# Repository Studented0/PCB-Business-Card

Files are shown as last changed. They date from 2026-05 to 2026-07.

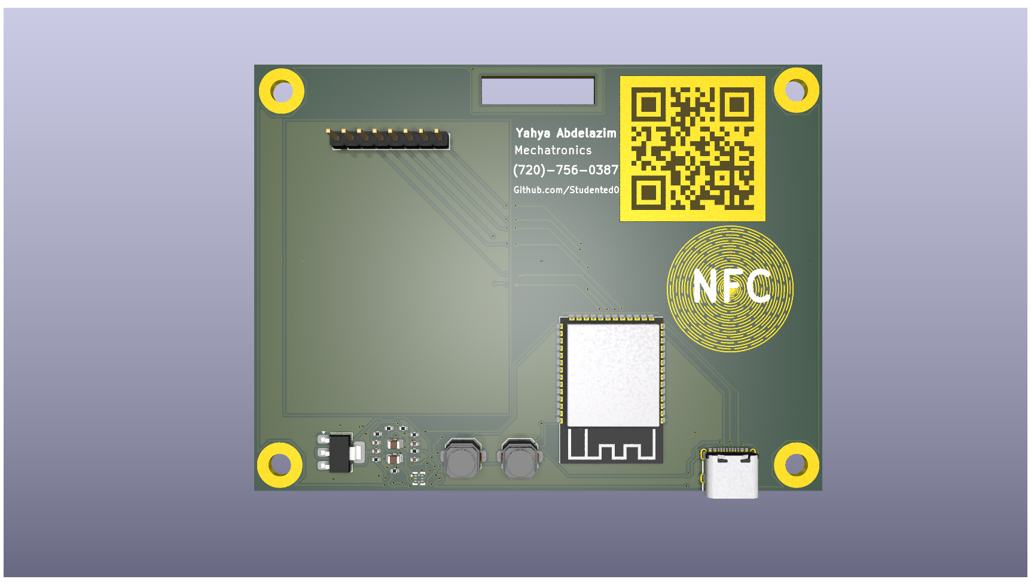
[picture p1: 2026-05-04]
productionold/lanyardpcbcard.png

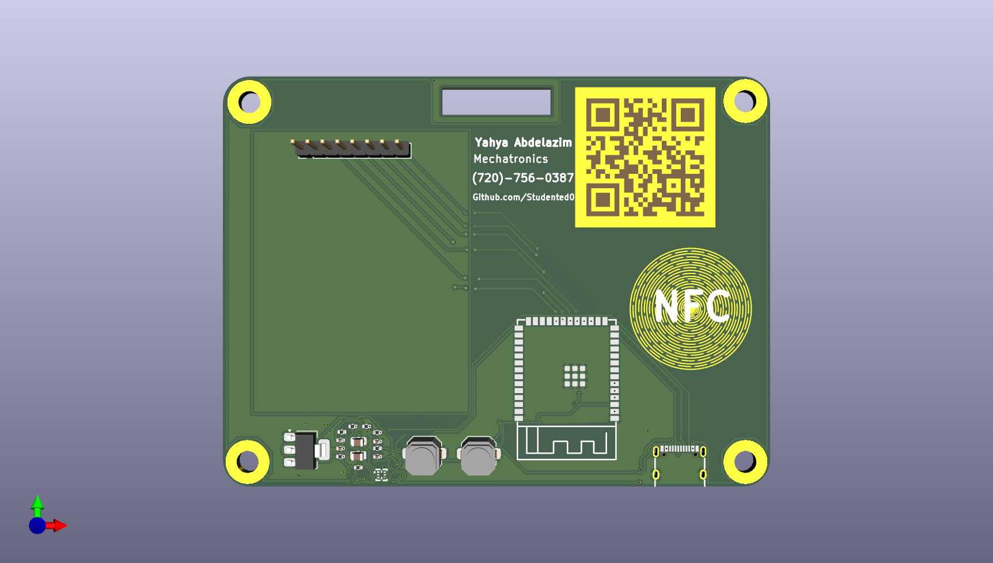
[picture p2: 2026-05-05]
Renders and CAD/lanyardpcbcard.png

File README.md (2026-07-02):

[PCB Business Card-bom.csv](https://github.com/user-attachments/files/27329266/PCB.Business.Card-bom.csv)
# PCB-Business-Card
 
A PCB Business card that shows your Spotify activity using lanyard in real time. Tap the card with a phone to show what song is playing on Spotify.
 
Powered over USB-C from a phone or any power bank. Connects to a phone hotspot (or any wifi) for the Lanyard WebSocket. 
 
## Screenshots


lanyardpcbcard

## Why I built this
 
I wanted a business card that has a cool twist. Plain cards feel boring to show and they are all the same. This one shows what I'm listening to, lets someone tap it to hear the same song, and has my GitHub a QR scan away. Business cards are supposed to grab people's attention, and I would say this one is different than other business cards.
 
## Hardware
 The ESP32 rewrites the NDEF URL every time a track changes over I2C, NT3H2111 (NFC Module) has I2C and RF interface simultaneously. When you are playing something NFC goes to spotify when nothing is playing goes to GitHub (for now). 100x75mm PCB. USB-C powers it with any power bank (im personally planning to use my phone). ESP32 is going to be hand soldered to save money but everything else is JLCPCB assembly 
 
## Wiring
 
| Signal | GPIO |
|---|---|
| DISP_MOSI | IO11 |
| DISP_SCLK | IO12 |
| DISP_CS | IO10 |
| DISP_DC | IO13 |
| DISP_RST | IO14 |
| DISP_BLK | IO9 |
| NFC_SDA | IO5 |
| NFC_SCL | IO6 |
| NFC_FD | IO4 |
| USB_DN | IO19 |
| USB_DP | IO20 |
| BOOT | IO0 |
| RESET | EN |
 
## Firmware
 
`firmware/main.ino` 
 
Libraries needed: TFT_eSPI, TJpg_Decoder, ArduinoWebsockets, ArduinoJson. Board: ESP32S3 Dev Module.
 
## Bill of Materials
 
SMD parts assembled by JLCPCB. ESP32 and the display are sourced separately.
 
| Component | Qty | LCSC | Note |
|---|-----|---|---|
| 100nF 0402 cap | 3 | C1525 | Basic |
| 10µF 0805 cap | 2 | C15850 | Basic |
| 56pF 0402 cap | 1 | C107007 | Extended — antenna tuning |
| 5.1kΩ 0402 resistor | 2 | C25905 | Basic — USB-C CC |
| 10kΩ 0402 resistor | 3 | C25744 | Basic — pullups |
| 4.7kΩ 0402 resistor | 2 | C25900 | Basic — I2C pullups |
| AMS1117-3.3 SOT-223 | 1 | C6186 | Basic |
| NT3H2111W0FHKH XQFN-8 | 1 | C710403 | Extended — NFC |
| TYPE-C 16PIN 2MD | 1 | C2765186 | Extended — USB-C |
| Tactile switch SMD | 2 | — | Extended |
 Name,Purpose,Quantity,Total Cost (USD),Link,Distributor
"Display","Displaying",1,14.00,"https://www.amazon.com/gp/product/B0GL1SWYP4/ref=ox_sc_act_title_1?smid=A2Z10KY0342329&psc=1","Amazon"
"ESP32-S3-WROOM-1-N4","microcontroller",1,5.21,"https://www.digikey.com/en/products/detail/espressif-systems/ESP32-S3-WROOM-1-N4/16162639","DIGIKEY"
"JLCPCB","PCB",1,25.59,"","JLCPCB"
| Component | Qty | Source |
|---|-----|---|
| ESP32-S3-WROOM-1-N8| 1 | Mouser Electronics |
| 2.0" ST7789V IPS 240×320 | 1 | Amazon |
 
## Repository Structure
 
```
PCB-Business-Card/
├── Firmware/
│   └── main.ino
├── lanyardpcbcard-backups/
├── libs/
│   └── easyeda/
│       ├── easyeda.3dshapes/
│       ├── easyeda.pretty/
│       └── easyeda.kicad_sym
├── production/
│   ├── backups/
│   ├── CPL-lanyardpcbcard.csv
│   ├── bom.csv
│   ├── lanyardpcbcard.step
│   ├── lanyardpcbcard.zip
│   └── ...
├── LICENSE
├── README.md
├── lanyardpcbcard.kicad_pcb
├── lanyardpcbcard.kicad_pro
├── lanyardpcbcard.kicad_sch
└── lanyardpcbcard.kicad_prl
```
 
## License
 
[MIT](LICENSE)

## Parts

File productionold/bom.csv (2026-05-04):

Designator | Footprint | Quantity | Value | LCSC Part #
C1, C3 | 0805 | 2 | 10µF
C2, C4, C5 | 0402 | 3 | 100nF
C6 | 0402 | 1 | 56pF
J1 | PinHeader_1x08_P2.54mm_Vertical | 1 | DISPLAY
R1, R2 | 0402 | 2 | 5.1k
R3, R4, R7 | 0402 | 3 | 10k
R5, R6 | 0402 | 2 | 4.7k
SW1 | SW_Push_1TS009xxxx-xxxx-xxxx_6x6x5mm | 1 | Reset
SW2 | SW_Push_1TS009xxxx-xxxx-xxxx_6x6x5mm | 1 | Boot
U1 | SOT-223-3_TabPin2 | 1 | AMS1117-3.3
U2 | WIRELM-SMD_ESP32-S3-WROOM-1 | 1 | ESP32-S3-WROOM-1 | C2913202
U3 | XQFN-8_L1.6-W1.6-P0.50-BL_NT3H2111W0FHKH | 1 | NT3H2111W0FHKH | C710403
USB1 | USB-C-SMD_TYPE-C-16PIN-2MD-073 | 1 | TYPE-C 16PIN 2MD | C2765186

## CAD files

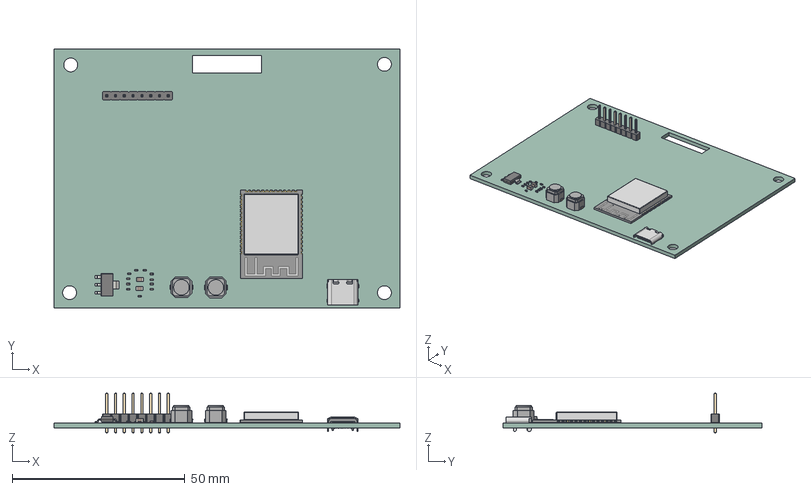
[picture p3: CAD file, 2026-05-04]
productionold/lanyardpcbcard.step
100.0 x 75.0 x 11.5 mm
C_0805_2012Metric x 2
R_0402_1005Metric x 7
C_0402_1005Metric x 4
pin_1 x 2
pin_2 x 2
PinHeader_1x08_P2.54mm_Vertical
SOT-223
USB-C-SMD_TYPE-C-6PIN-2MD-073
WIRELM-SMD_ESP32-S3-WROOM-1
lanyardpcbcard_PCB

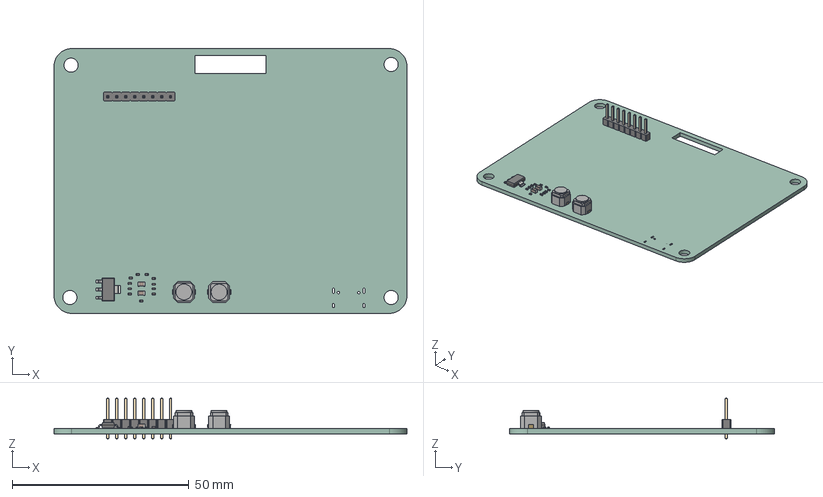
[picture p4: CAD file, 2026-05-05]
Renders and CAD/lanyardpcbcard.step
100.0 x 75.0 x 11.5 mm
C_0805_2012Metric x 2
R_0402_1005Metric x 7
C_0402_1005Metric x 4
pin_1 x 2
pin_2 x 2
PinHeader_1x08_P2.54mm_Vertical
SOT-223
lanyardpcbcard_PCB

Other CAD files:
Renders and CAD/lanyardpcbcard.stl
productionold/lanyardpcbcard.stl

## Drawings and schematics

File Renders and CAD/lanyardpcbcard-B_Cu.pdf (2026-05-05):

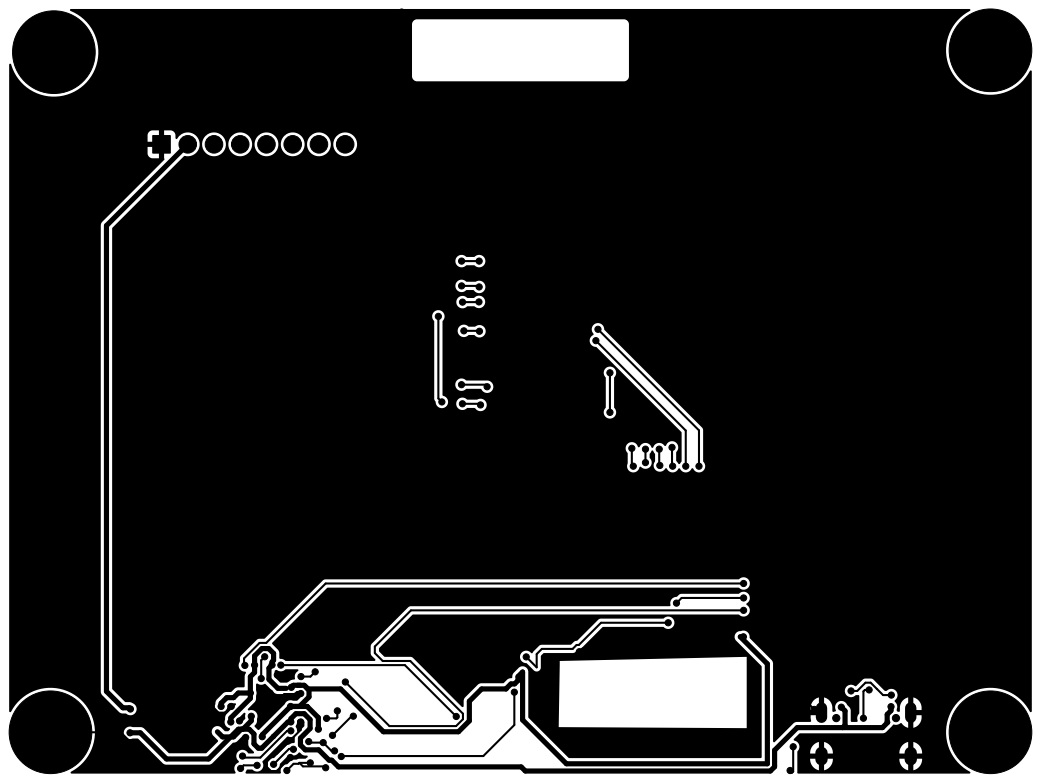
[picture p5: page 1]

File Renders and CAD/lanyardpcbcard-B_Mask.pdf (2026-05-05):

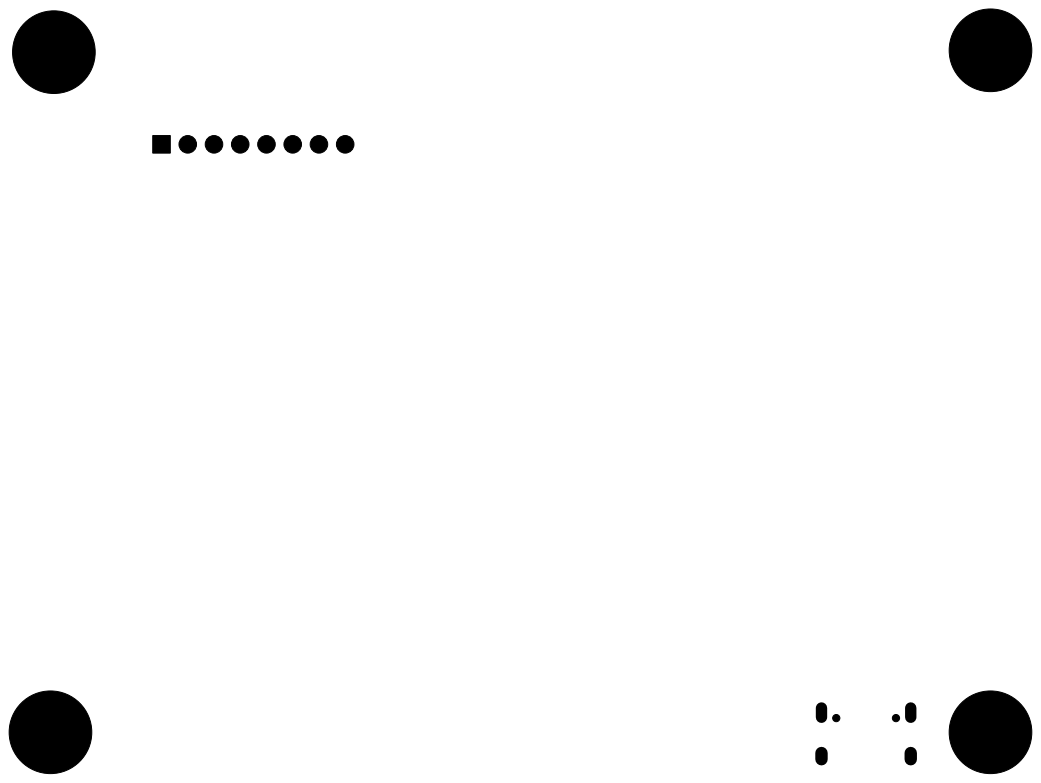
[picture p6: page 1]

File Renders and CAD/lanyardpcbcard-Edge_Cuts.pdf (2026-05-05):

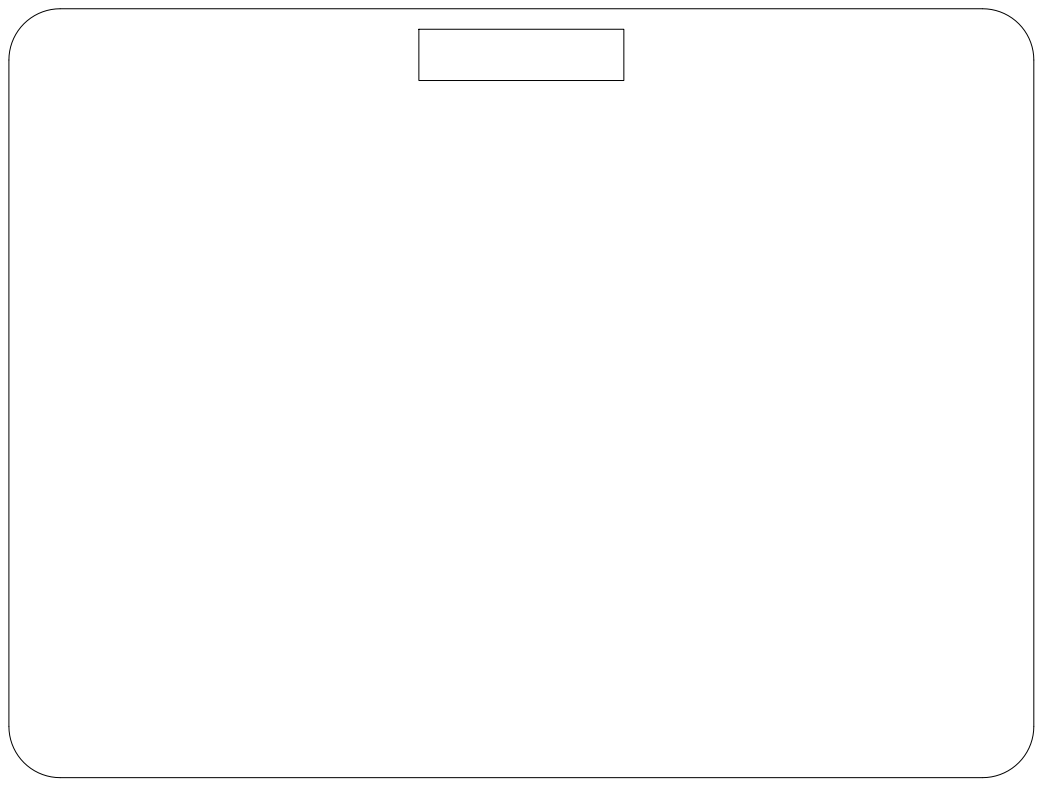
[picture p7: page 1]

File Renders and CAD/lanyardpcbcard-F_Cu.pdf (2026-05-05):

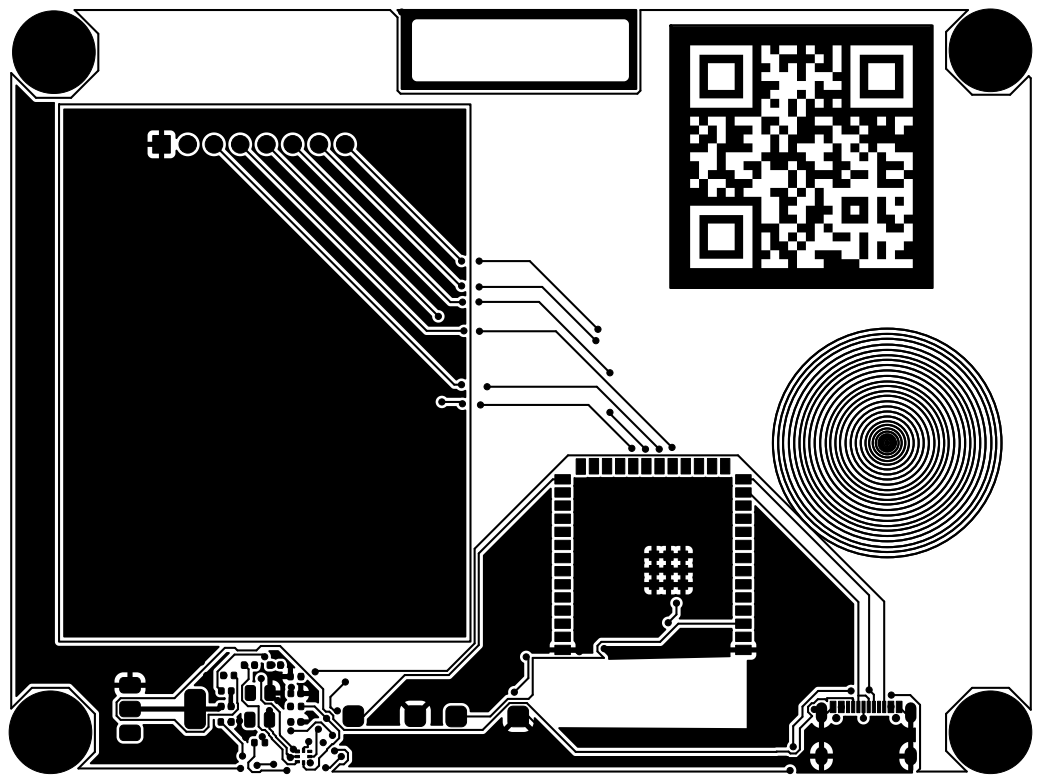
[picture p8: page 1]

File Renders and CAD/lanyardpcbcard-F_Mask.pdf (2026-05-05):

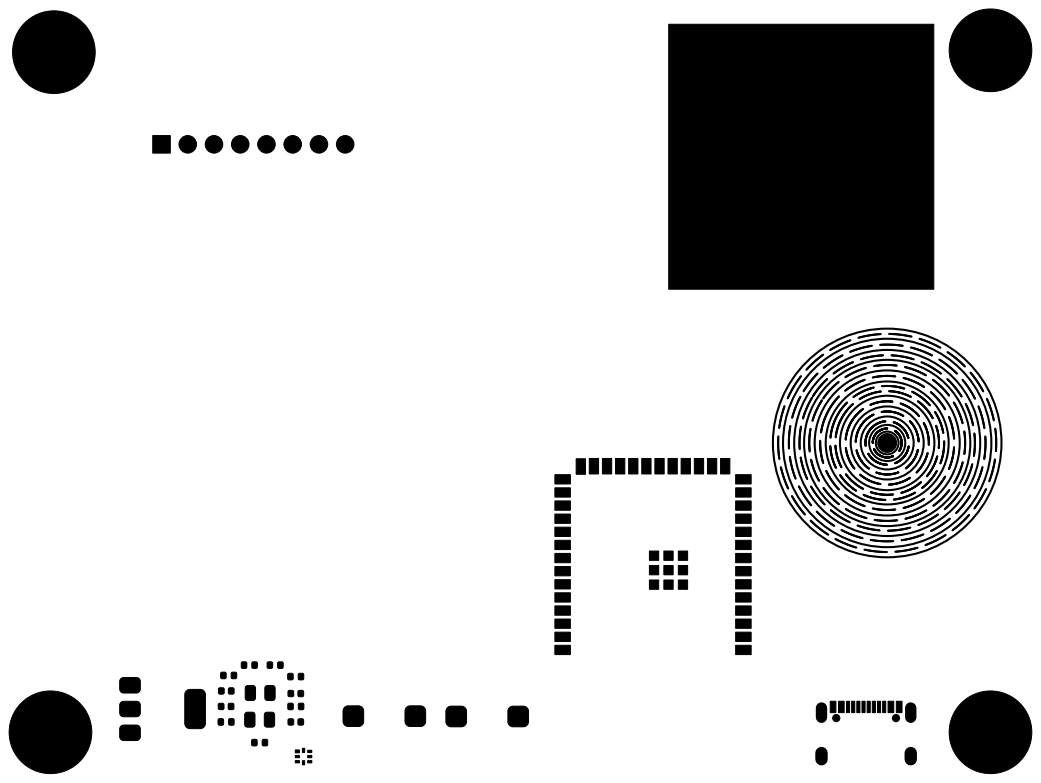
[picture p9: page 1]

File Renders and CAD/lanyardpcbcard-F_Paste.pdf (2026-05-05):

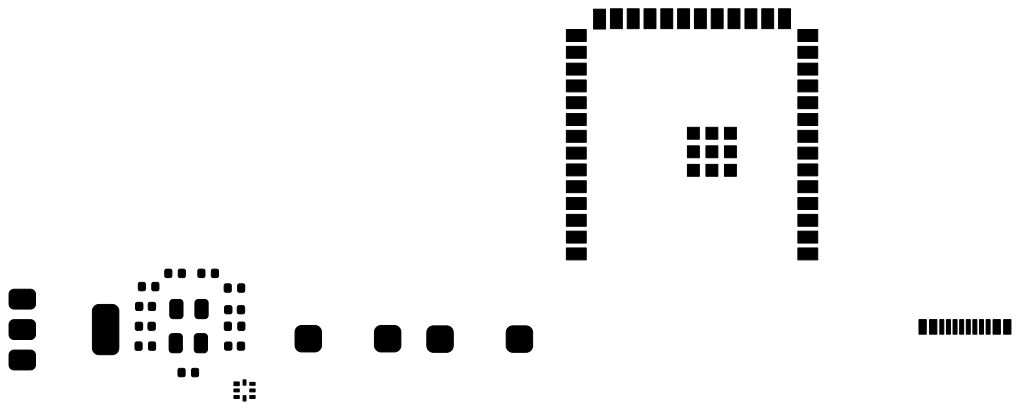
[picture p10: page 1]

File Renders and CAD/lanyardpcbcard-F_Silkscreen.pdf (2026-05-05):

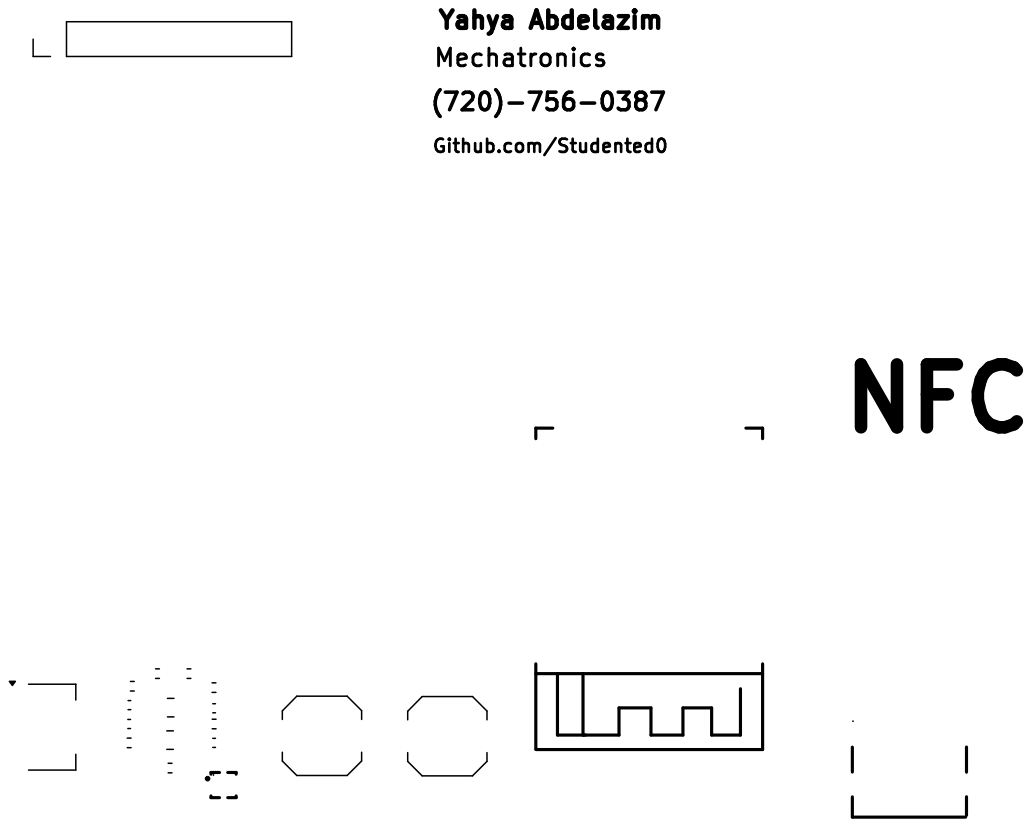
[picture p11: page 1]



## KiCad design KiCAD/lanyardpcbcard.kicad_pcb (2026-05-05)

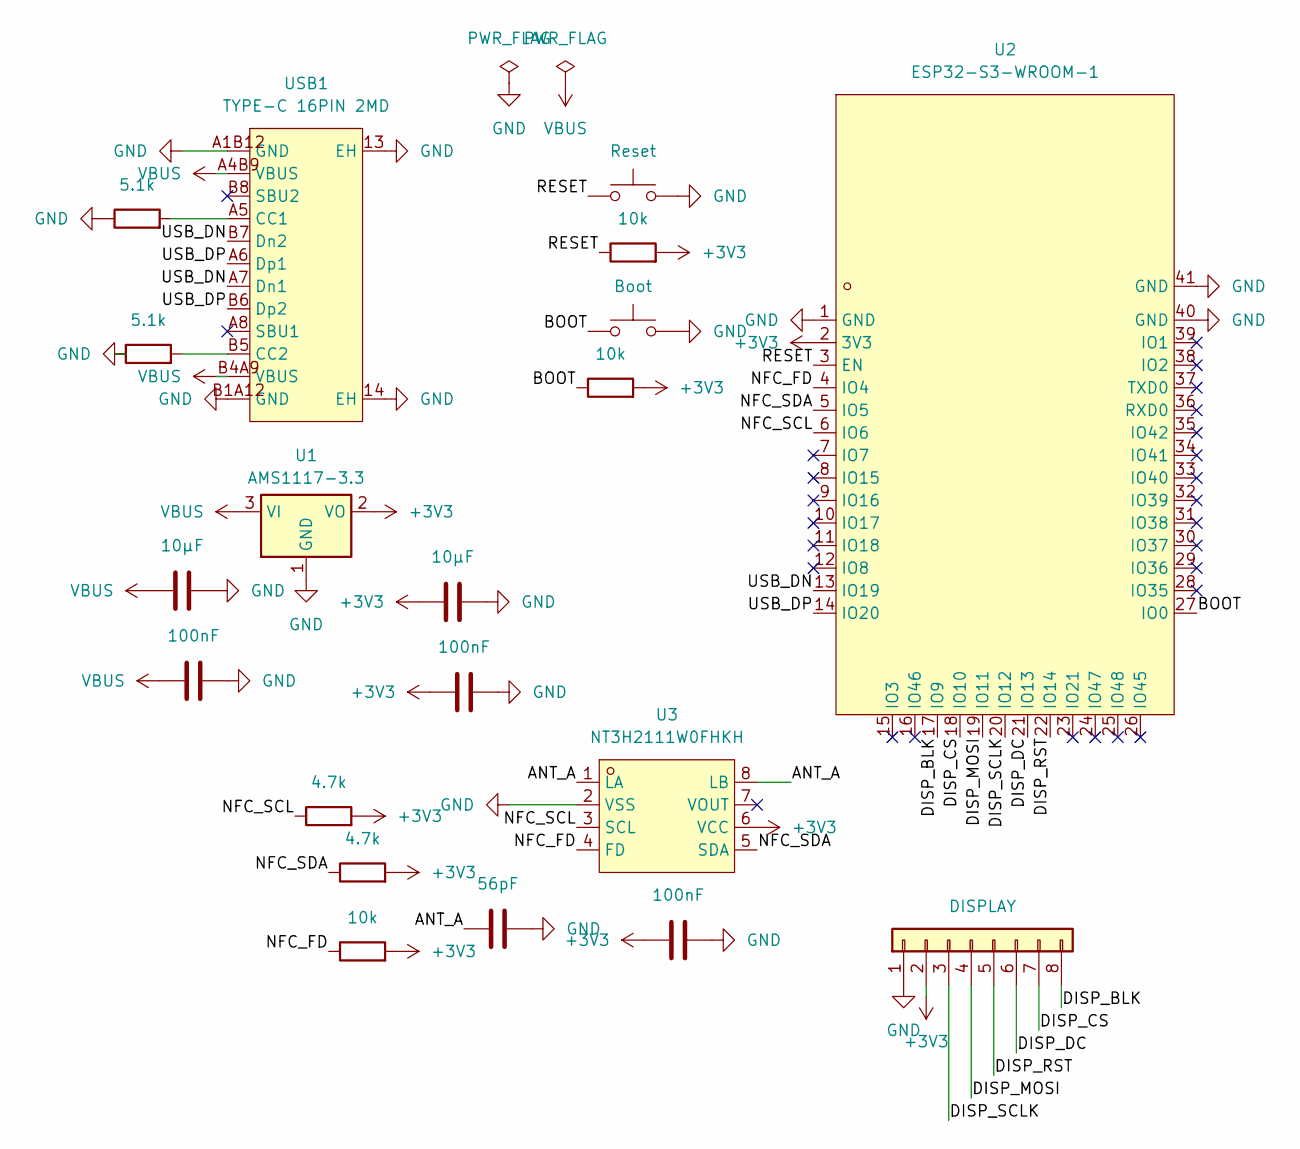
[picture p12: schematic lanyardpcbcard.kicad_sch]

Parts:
C1, C3: 10µF; C_0805_2012Metric
C2, C4, C5: 100nF; C_0402_1005Metric
C6: 56pF; C_0402_1005Metric
J1: DISPLAY; PinHeader_1x08_P2.54mm_Vertical
R1, R2: 5.1k; R_0402_1005Metric
R3, R4, R7: 10k; R_0402_1005Metric
R5, R6: 4.7k; R_0402_1005Metric
SW1: Reset; SW_Push_1TS009xxxx-xxxx-xxxx_6x6x5mm
SW2: Boot; SW_Push_1TS009xxxx-xxxx-xxxx_6x6x5mm
U1: AMS1117-3.3; SOT-223-3_TabPin2
U2: ESP32-S3-WROOM-1; WIRELM-SMD_ESP32-S3-WROOM-1; MPN ESP32-S3-WROOM-1-N16R8; LCSC Part C2913202
U3: NT3H2111W0FHKH; XQFN-8_L1.6-W1.6-P0.50-BL_NT3H2111W0FHKH; MPN NT3H2111W0FHKH; LCSC Part C710403
USB1: TYPE-C 16PIN 2MD; USB-C-SMD_TYPE-C-16PIN-2MD-073; MPN TYPE-C 16PIN 2MD(073); LCSC Part C2765186

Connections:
+3V3: C3.1, C4.1, C5.1, J1.2, R3.2, R4.2, R5.2, R6.2, R7.2, U1.2 (VO), U2.2 (3V3), U3.6 (VCC)
/ANT_A: C6.1, U3.1 (LA), U3.8 (LB)
/BOOT: R4.1, SW2.1, U2.27 (IO0)
/DISP_BLK: J1.8, U2.17 (IO9)
/DISP_CS: J1.7, U2.18 (IO10)
/DISP_DC: J1.6, U2.21 (IO13)
/DISP_MOSI: J1.4, U2.19 (IO11)
/DISP_RST: J1.5, U2.22 (IO14)
/DISP_SCLK: J1.3, U2.20 (IO12)
/NFC_FD: R7.1, U2.4 (IO4), U3.4 (FD)
/NFC_SCL: R5.1, U2.6 (IO6), U3.3 (SCL)
/NFC_SDA: R6.1, U2.5 (IO5), U3.5 (SDA)
/RESET: R3.1, SW1.1, U2.3 (EN)
/USB_DN: U2.13 (IO19), USB1.A7 (Dn1), USB1.B7 (Dn2)
/USB_DP: U2.14 (IO20), USB1.A6 (Dp1), USB1.B6 (Dp2)
GND: C1.2, C2.2, C3.2, C4.2, C5.2, C6.2, J1.1, R1.1, R2.1, SW1.2, SW2.2, U1.1 (GND), U2.1 (GND), U2.40 (GND), U2.41 (GND), U3.2 (VSS), USB1.13 (EH), USB1.14 (EH), USB1.A1B12 (GND), USB1.B1A12 (GND)
unnamed: R1.2, USB1.A5 (CC1)
unnamed: R2.2, USB1.B5 (CC2)
VBUS: C1.1, C2.1, U1.3 (VI), USB1.A4B9 (VBUS), USB1.B4A9 (VBUS)

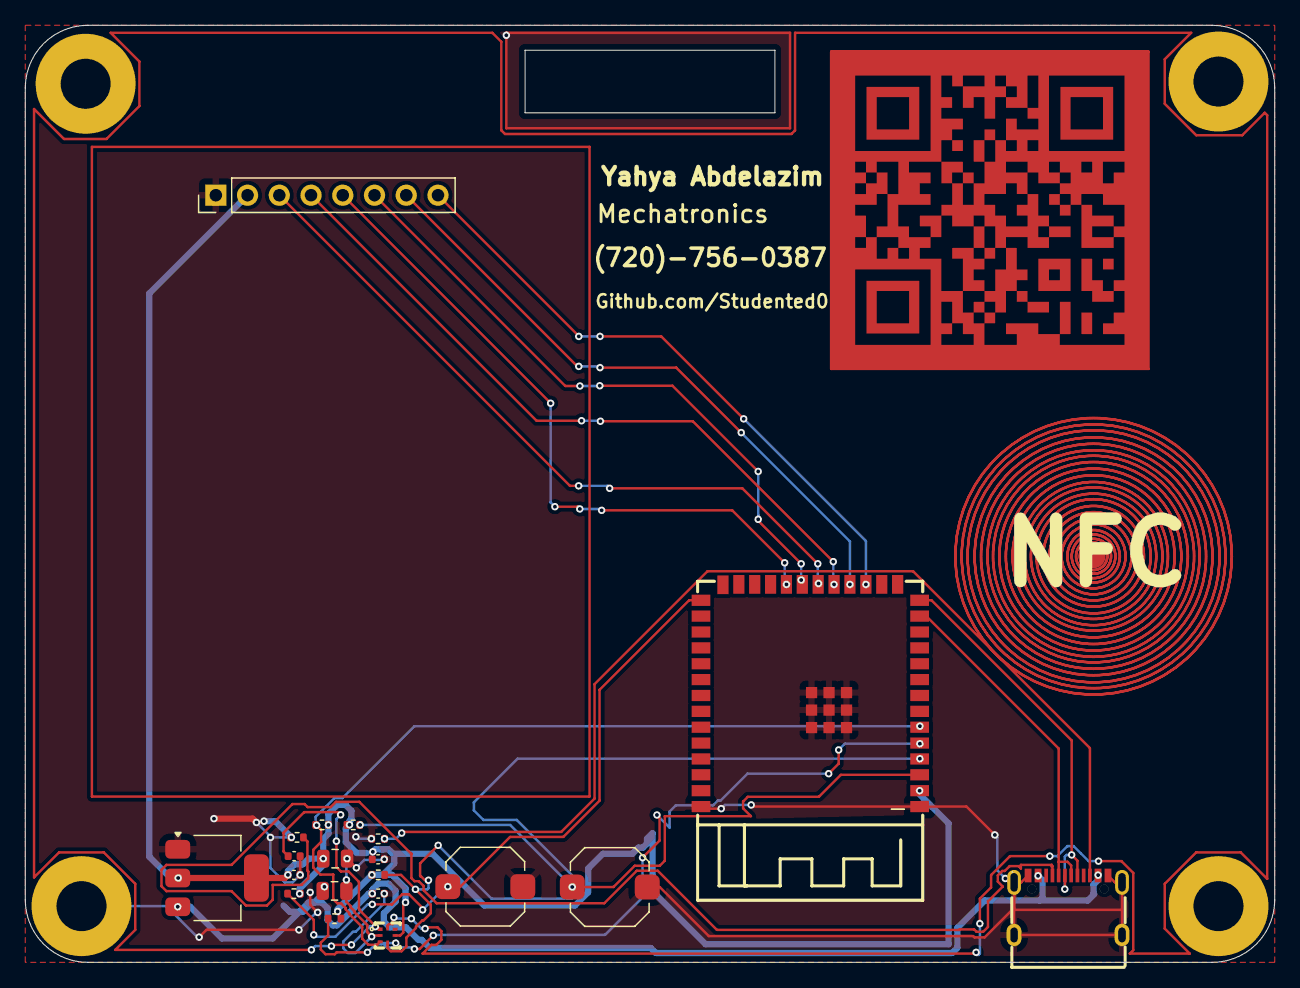
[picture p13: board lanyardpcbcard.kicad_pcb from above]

Board: 2 copper layers, 100.0 x 75.0 mm, 20 parts (0 on the bottom side), 19 nets.

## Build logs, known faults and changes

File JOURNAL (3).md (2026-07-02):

<!--
  This journal is auto generated by Stasis.
-->

# 5/5/2026 4 PM - Updated PCB, README, And ordered parts

_Time spent: 1h_

In this session I rewrote the README fully by hand, FIlleted the PCB, and ordered all the parts as I will request reimbursment of the 50 and pay the 6 on my own. The updated PCB is below. (It will be Black)
lanyardpcbcard



# 5/4/2026 3 AM - JLCPCB, BOM, and GitHub

_Time spent: 3.25h_

Exported everything using the Fabrication Toolkit plugin for KiCad. The BOM matching on JLCPCB was not very easy. Several parts didn't auto-match correctly. The resistors showed zero stock even though they exist as basic parts, had to search each value manually and select them. The display header got matched to a completely wrong part, a 1.28" round LCD module, so I deselected it entirely since I'm plugging the display in myself anyway.
Then the price came up as $67. The breakdown was $25 setup fee, $16 feeder loading fee, and the rest was components and assembly. Switching to economic assembly dropped it significantly but the ESP32-S3-WROOM-1 is marked as Standard Only on JLCPCB . So I removed it from the assembly order and I'll solder it myself when the board arrives. Castellated pads are actually not that hard to hand solder with flux. That brought the price down to around $21 for the assembled board without the ESP32.
The ESP32 I'm ordering separately from DigiKey. $5.21 for the chip plus $6.99 FedEx Ground shipping, $12.72 total. Annoying to pay separate shipping but it's still way cheaper than the $67 standard assembly quote.
Setting up the GitHub repo and pushing everything was straightforward. The repo has the KiCad files in the root, production files in the production folder, firmware in the Firmware folder, and the easyeda library in libs/easyeda. BOM.csv in the root links to the LCSC part numbers for everything JLCPCB assembles.





# 5/4/2026 3 AM - PCB Layout and Routing

_Time spent: 3.25h_

Layout started with setting the board size to 100×75mm. That fits JLCPCB's economic assembly limit and is pretty similar to a SATA SSD.
The first thing I placed was the display connector. The 2.0" ST7789V module from Amazon has a footprint that takes up almost the entire top half of the board. I didn't expect that. It actually worked out well because now the card has a clear right half that's just the screen and a left half where all the components live. 
I added a copper QR code using KiCad's image converter tool. That process was a disaster. The first import came in as a giant pink rectangle covering half the board. Try again with different scale. Then the inversion was wrong, the QR was solid copper with dark cutouts instead of copper squares on green. Spent way too long trying to flip it. Eventually accepted the current version which actually looks fine as exposed copper on black PCB. Added a soldermask opening over it so it shows as bare metal.
The NFC antenna coil went on B.Cu as a two-turn rectangular loop around the board perimeter. I started routing it on F.Cu but moved it to the back so the decorative copper circles on the front wouldn't interfere with the antenna field. The circles are purely aesthetic, no net assigned, just exposed copper art. I was worried they'd kill the NFC range but at tap distance it should be fine.
Routing was honestly pretty bad. I used push-and-shove mode and just connected everything. Power traces are 0.5mm, signals are 0.2mm, and pours on both layers handle GND. There are a few ugly detours, but zero unconnected nets. 
I added four mounting holes at the corners and a lanyard slot cutout on Edge.Cuts at the top center. The slot means you can clip a lanyard directly to the board without a separate hole. Added silkscreen text for my name, Mechatronics, phone number, and GitHub handle between the display and the QR code.

lanyardpcbcard



# 5/4/2026 3 AM - Planning and Schematic

_Time spent: 3.5h_

I wanted to build a PCB business card but make it cool. It shows my Spotify activity from Discord using Lanyard(other Discord activities too), let people tap it with their phone to open the song I'm listening to, and have a QR code on the board that links to my GitHub(for now the its set to a bit.ly). I also wanted it to be wearable as a lanyard.
The first thing I had to figure out was the MCU. I almost went with the ESP32-C3 Mini but that would have been a mistake. The C3 doesn't have enough RAM to hold a JPEG decoder, a WiFi stack, TLS buffers, and a frame buffer at the same time. The ESP32-S3-WROOM-1 has PSRAM built in so it can actually handle all of that. That decision alone probably saved me from a board that would OOM every time album art loaded.
Finding parts took longer than I expected. I wanted everything on JLCPCB's basic parts list to keep costs down. Spent a while searching for a basic USB-C connector with data lines, there was none. Ended up just putting the extended fee for three parts, the ESP32, the NT3H2111 NFC chip, and the USB-C connector. The NFC chip I picked is the NT3H2111. It has an I2C interface so the ESP32 can write to it directly. Every time Lanyard fires a track update the ESP32 rewrites the NDEF URL to the Spotify track link. When nothing is playing it writes my GitHub URL instead. I also wired the Field Detect pin to a GPIO so the firmware knows when someone is actively tapping the card.
Schematic went mostly fine. The power tree was straightforward, USB-C with 5.1k CC resistors, AMS1117-3.3 LDO, decoupling caps everywhere. The ESP32 programs over its native USB peripheral on IO19 and IO20 so no CH340 or CP2102 needed. That saved an extended part fee and simplified the board.
The antenna schematic took a little too long to get right. The NT3H2111 has two antenna pins, LA and LB. I kept going back and forth on whether they should be two different nets or the same net. The answer is they're the same net, the antenna coil is a continuous loop from LA around the board back to LB, and since KiCad won't route between different nets I had to make them both the same net. The 56pF tuning cap goes from ANT to GND. Took way longer than it should have to figure that out.





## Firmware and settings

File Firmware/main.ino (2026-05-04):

#include <Arduino.h>
#include <WiFi.h>
#include <WiFiClientSecure.h>
#include <ArduinoWebsockets.h>
#include <ArduinoJson.h>
#include <TFT_eSPI.h>
#include <TJpg_Decoder.h>
#include <HTTPClient.h>
#include <Wire.h>
#include <time.h>

#define NFC_SDA 5
#define NFC_SCL 6
#define NFC_FD  4

const char* WIFI_SSID = "YOUR_SSID";
const char* WIFI_PASS = "YOUR_PASSWORD";
const char* DISCORD_USER_ID = "YOUR_ID";
const char* GITHUB_URL = "https://github.com/Studented0";
const char* NTP_SERVER = "pool.ntp.org";

using namespace websockets;

TFT_eSPI tft = TFT_eSPI();
WebsocketsClient ws;

String currentTrackId = "";
String currentTitle = "";
String currentArtist = "";
String currentAlbumArt = "";
long timestampStart = 0;
long timestampEnd = 0;
bool isPlaying = false;

bool tftOutput(int16_t x, int16_t y, uint16_t w, uint16_t h, uint16_t* bitmap) {
    tft.pushImage(x, y, w, h, bitmap);
    return true;
}

void writeNFC(const char* url) {
    Wire.beginTransmission(0x55);
    Wire.endTransmission();
}

void fetchAndDisplayAlbumArt(String url) {
    HTTPClient http;
    http.begin(url);
    int code = http.GET();
    if (code == 200) {
        WiFiClient* stream = http.getStreamPtr();
        TJpgDec.drawJpg(0, 0, (const uint8_t*)stream, http.getSize());
    }
    http.end();
}

void displayNowPlaying() {
    tft.fillRect(0, 240, 240, 80, TFT_BLACK);
    tft.setTextColor(TFT_WHITE);
    tft.setTextSize(1);
    tft.setCursor(0, 245);
    tft.println(currentTitle);
    tft.println(currentArtist);
}

void displayProgressBar() {
    long now = time(nullptr) * 1000L;
    long progress = now - timestampStart;
    long duration = timestampEnd - timestampStart;
    int barWidth = map(progress, 0, duration, 0, 240);
    tft.fillRect(0, 310, barWidth, 4, TFT_GREEN);
    tft.fillRect(barWidth, 310, 240 - barWidth, 4, TFT_DARKGREY);
}

void displayIdle() {
    tft.fillScreen(TFT_BLACK);
    tft.setTextColor(TFT_WHITE);
    tft.setCursor(20, 100);
    tft.println("Yahya Abdelazim");
    tft.setCursor(20, 120);
    tft.println("github.com/Studented0");
    writeNFC(GITHUB_URL);
}

void handleLanyardMessage(WebsocketsMessage msg) {
    JsonDocument doc;
    deserializeJson(doc, msg.data());
    
    int op = doc["op"];
    
    if (op == 1) {
        ws.send("{\"op\":2,\"d\":{\"subscribe_to_id\":\"" + String(DISCORD_USER_ID) + "\"}}");
    }
    
    if (op == 0) {
        JsonObject spotify = doc["d"]["spotify"];
        
        if (spotify.isNull()) {
            isPlaying = false;
            displayIdle();
            return;
        }
        
        isPlaying = true;
        currentTitle = spotify["song"].as<String>();
        currentArtist = spotify["artist"].as<String>();
        currentAlbumArt = spotify["album_art_url"].as<String>();
        timestampStart = spotify["timestamps"]["start"].as<long>();
        timestampEnd = spotify["timestamps"]["end"].as<long>();
        
        String trackUrl = spotify["track_id"].as<String>();
        String nfcUrl = "https://open.spotify.com/track/" + trackUrl;
        writeNFC(nfcUrl.c_str());
        
        fetchAndDisplayAlbumArt(currentAlbumArt);
        displayNowPlaying();
    }
}

void setup() {
    Serial.begin(115200);
    
    Wire.begin(NFC_SDA, NFC_SCL);
    
    tft.init();
    tft.setRotation(0);
    tft.fillScreen(TFT_BLACK);
    
    TJpgDec.setJpgScale(1);
    TJpgDec.setCallback(tftOutput);
    
    WiFi.begin(WIFI_SSID, WIFI_PASS);
    while (WiFi.status() != WL_CONNECTED) delay(500);
    
    configTime(0, 0, NTP_SERVER);
    while (time(nullptr) < 1000) delay(100);
    
    ws.onMessage(handleLanyardMessage);
    ws.connect("wss://api.lanyard.rest/socket");
}

void loop() {
    ws.poll();
    
    if (isPlaying) {
        displayProgressBar();
    }
    
    if (WiFi.status() != WL_CONNECTED) {
        WiFi.reconnect();
    }
    
    if (!ws.available()) {
        ws.connect("wss://api.lanyard.rest/socket");
    }
    
    delay(100);
}

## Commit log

2026-05-04 Initial design files - schematic, PCB layout, firmware skeleton
    [bom.csv, designators.csv, lanyardpcbcard.kicad_pcb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]
2026-05-04 Enhance README with detailed project information
    Expanded the README to provide detailed information about the PCB business card features, hardware specifications, NFC functionality, progress bar calculations, wiring details, firmware requirements,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
2026-05-04 Update README with BOM link and component details
    Added a link to the BOM CSV file and updated the components table with additional details.
2026-05-05 Regenerated production files, rounded corners, updated BOM
    [bom.csv, designators.csv, lanyardpcbcard.kicad_pcb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]
2026-07-02 organizing files
    [lanyardpcbcard.kicad_pcb, lanyardpcbcard.kicad_sch, lanyardpcbcard.step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]
